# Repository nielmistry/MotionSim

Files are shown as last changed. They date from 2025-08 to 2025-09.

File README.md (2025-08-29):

# DIY Motion Simulator

This project provides a comprehensive guide to building a low-cost DIY motion simulator for flying RC planes and simulator games. Combining woodworking and mechatronics, it offers an affordable alternative to commercial options. The documentation includes CAD models, detailed assembly instructions, and software setup.

Support This Project: [Patreon](https://patreon.com/MichaelRechtin)

## Features
- Compatible with flight simulation games like Microsoft Flight Simulator 2020/2024 and WarThunder.
- Support for RC planes using ArduPilot.
- Modular design for portability, using a universal joint for base and chair connection.
- Open-source software and hardware design.

## Disclaimer
This is a DIY project; individual modifications may be necessary due to part availability or unique requirements. Ensure proper safety precautions, and consult professionals when needed. The author is not liable for any issues arising from the build.

## Getting Started
1. **CAD Models**: Access the full CAD design [here](https://cad.onshape.com/documents/14465a5308115755a641bf91/w/473302792caf9fe5237c9eca/e/42b5f99c290e18c70798f158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).
2. **Bill of Materials**: Refer to the detailed parts list in the documentation for all required components.
3. **Tools Required**:
   - Saws (e.g., circular, jigsaw, CNC router)
   - Power drill, impact driver
   - Soldering iron, 3D printer

## Assembly
The simulator comprises two main parts:
- **Base Assembly**: Includes motor mounts, universal joint, and support structures.
- **Chair Assembly**: Features side panels, foot supports, and a universal joint for connection to the base.

Follow the detailed step-by-step instructions in the documentation.

## Electronics and Wiring
The wiring for the simulator includes:
- Motion base wiring for motors and drivers.
- Side compartment wiring for controller integration.
- Back panel connectors for ease of disassembly.

Ensure proper orientation and connections for the MPU6050 sensor and other components.

## Software Setup
- **Teensy 4.0**: Flash the provided C++ code to control pitch and roll motors.
- **Raspberry Pi**: Configure USB flight controls and autorun scripts for seamless operation.
- **PC Integration**: Install necessary Python packages for supported games. Full code and instructions are available on the [GitHub repository](https://github.com/MichaelRechtin/MotionSim).

## Supported Games and Modes
- **Simulator Games**: Microsoft Flight Simulator 2020/2024, WarThunder
- **RC Planes**: Integration with Ardupilot and MAVLINK configurations

## Additional Features
- Optional integration with Buttkicker for enhanced gaming experience.
- Flexible wiring options for custom setups.

## Resources
- [Detailed Documentation](./DIY%20Motion%20Simulator%20Documentation.pdf)
- [PCB CI/CD Documentation](./docs/PCB_CI_CD.md) - Automated PCB manufacturing file generation
- [GitHub Repository](https://github.com/MichaelRechtin/MotionSim)
- [Bill of Materials](#)

### PCB Manufacturing

This repository includes automated CI/CD workflows for generating PCB manufacturing files:

- **Automated Gerber Generation**: Manufacturing files are automatically generated from KiCad PCB designs
- **Release Management**: Semantic versioning triggers automatic GitHub releases with PCB files
- **Local Generation**: Use `./generate-pcb-files.sh` to generate files locally

See [PCB CI/CD Documentation](./docs/PCB_CI_CD.md) for detailed information.

---

Feel free to explore, modify, and enjoy your DIY Motion Simulator!

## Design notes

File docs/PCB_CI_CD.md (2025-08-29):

# PCB CI/CD Workflows

This repository includes automated CI/CD workflows for generating manufacturing files from KiCad PCB designs.

## 🔧 Automated Workflows

### Pull Request Workflow (`pcb-build.yml`)

**Triggers:** When PCB files in `MotionSimPCB/` are modified in pull requests

**Generates:**
- PDF files from schematics and PCB layout
- Gerber files for PCB manufacturing
- Excellon drill files
- Manufacturing-ready ZIP packages

**Output:** GitHub Actions artifacts with download links automatically posted as PR comments

### Release Workflow (`release.yml`)

**Triggers:** When semantic version tags are pushed (e.g., `v1.0.0`, `v2.1.3`)

**Generates:**
- Versioned PDFs package
- Manufacturing files package
- Complete package with all files
- GitHub release with attached files

**Output:** GitHub release page with downloadable manufacturing files

### Test Workflow (`test-pcb.yml`)

**Triggers:** Manual dispatch or when workflow files are modified

**Purpose:** Validates KiCad setup and tests generation capabilities

## 📁 Generated Files

### PDFs
- `MotionSimPCB-schematic.pdf` - Main schematic diagram
- `controllers-schematic.pdf` - Controllers schematic diagram
- `MotionSimPCB-pcb.pdf` - PCB layout (when generation succeeds)

### Manufacturing Files
- `*.gbr` files - Gerber files for each PCB layer
- `*.drl` files - Excellon drill files
- ZIP packages ready for PCB manufacturers

## 🚀 Usage

### For Contributors (Pull Requests)

1. Modify PCB files in `MotionSimPCB/` directory
2. Create a pull request
3. Wait for CI to complete (usually 2-5 minutes)
4. Download artifacts from the PR comment links
5. Review generated PDFs and manufacturing files

### For Releases

1. Ensure all changes are merged to main branch
2. Create a semantic version tag:
   ```bash
   git tag v1.0.0
   git push origin v1.0.0
   ```
3. GitHub will automatically create a release with manufacturing files
4. Release files are ready for PCB manufacturers

### For Local Generation

Use the included script for local generation:

```bash
./generate-pcb-files.sh
```

**Requirements:**
- Docker installed and running
- PCB files in `MotionSimPCB/` directory

## 🛠️ Manual PCB Manufacturing

If automated generation fails or you prefer manual control:

### Using KiCad GUI

1. **Install KiCad** (version 9.0 or compatible)

2. **Open PCB file:**
   - Launch KiCad
   - Open `MotionSimPCB/MotionSimPCB.kicad_pcb`

3. **Generate Gerber files:**
   - Go to `File > Fabrication Outputs > Gerbers`
   - Select layers:
     - F.Cu (Front Copper)
     - B.Cu (Back Copper)
     - F.Paste (Front Paste)
     - B.Paste (Back Paste)
     - F.Silkscreen (Front Silkscreen)
     - B.Silkscreen (Back Silkscreen)
     - F.Mask (Front Solder Mask)
     - B.Mask (Back Solder Mask)
     - Edge.Cuts (Board Outline)
   - Click "Plot"

4. **Generate drill files:**
   - Go to `File > Fabrication Outputs > Drill Files`
   - Select Excellon format
   - Click "Generate Drill File"

5. **Package for manufacturer:**
   - Zip all `.gbr` and `.drl` files
   - Send to your PCB manufacturer

### PCB Specifications

- **Type:** 2-layer PCB
- **Thickness:** 1.6mm (standard)
- **Surface Finish:** HASL or ENIG recommended
- **Solder Mask:** Green (standard)
- **Silkscreen:** White
- **Via Fill:** Tented vias recommended

## 🔍 Troubleshooting

### Common Issues

**"KiCad generation failed"**
- The workflow will fall back to existing PDFs
- Check the Actions log for detailed error messages
- Use the local generation script for debugging

**"No artifacts available"**
- Ensure PCB files were actually modified in the PR
- Check that file paths match `MotionSimPCB/**`

**Permission errors in local generation**
- Ensure Docker has sufficient permissions
- Try running with `sudo` if necessary
- Check that PCB files are readable

### Getting Help

1. Check the GitHub Actions logs for detailed error messages
2. Review the PCB files for any format compatibility issues
3. Try the local generation script to isolate Docker issues
4. Open an issue if problems persist

## 🔄 Updating Workflows

The workflows are designed to be robust and self-contained. Key features:

- **Fallback mechanisms:** Uses existing PDFs if generation fails
- **Version compatibility:** Uses KiCad 9.0 matching the file format
- **Error handling:** Graceful degradation with informative messages
- **Local testing:** Standalone script for development and debugging

## 📋 File Structure

```
MotionSimPCB/
├── MotionSimPCB.kicad_pcb    # Main PCB layout
├── MotionSimPCB.kicad_sch    # Main schematic
├── controllers.kicad_sch     # Controllers schematic
├── MotionSimPCB.kicad_pro    # Project file
└── pdfs/                     # Existing PDFs (fallback)
    └── MotionSimPCB.pdf

assets/                       # Generated files (gitignored)
├── pdfs/                     # Generated PDFs
├── gerbers/                  # Generated Gerber files
└── drill/                    # Generated drill files

.github/workflows/
├── pcb-build.yml            # PR workflow
├── release.yml              # Release workflow
└── test-pcb.yml             # Test workflow

generate-pcb-files.sh        # Local generation script
```

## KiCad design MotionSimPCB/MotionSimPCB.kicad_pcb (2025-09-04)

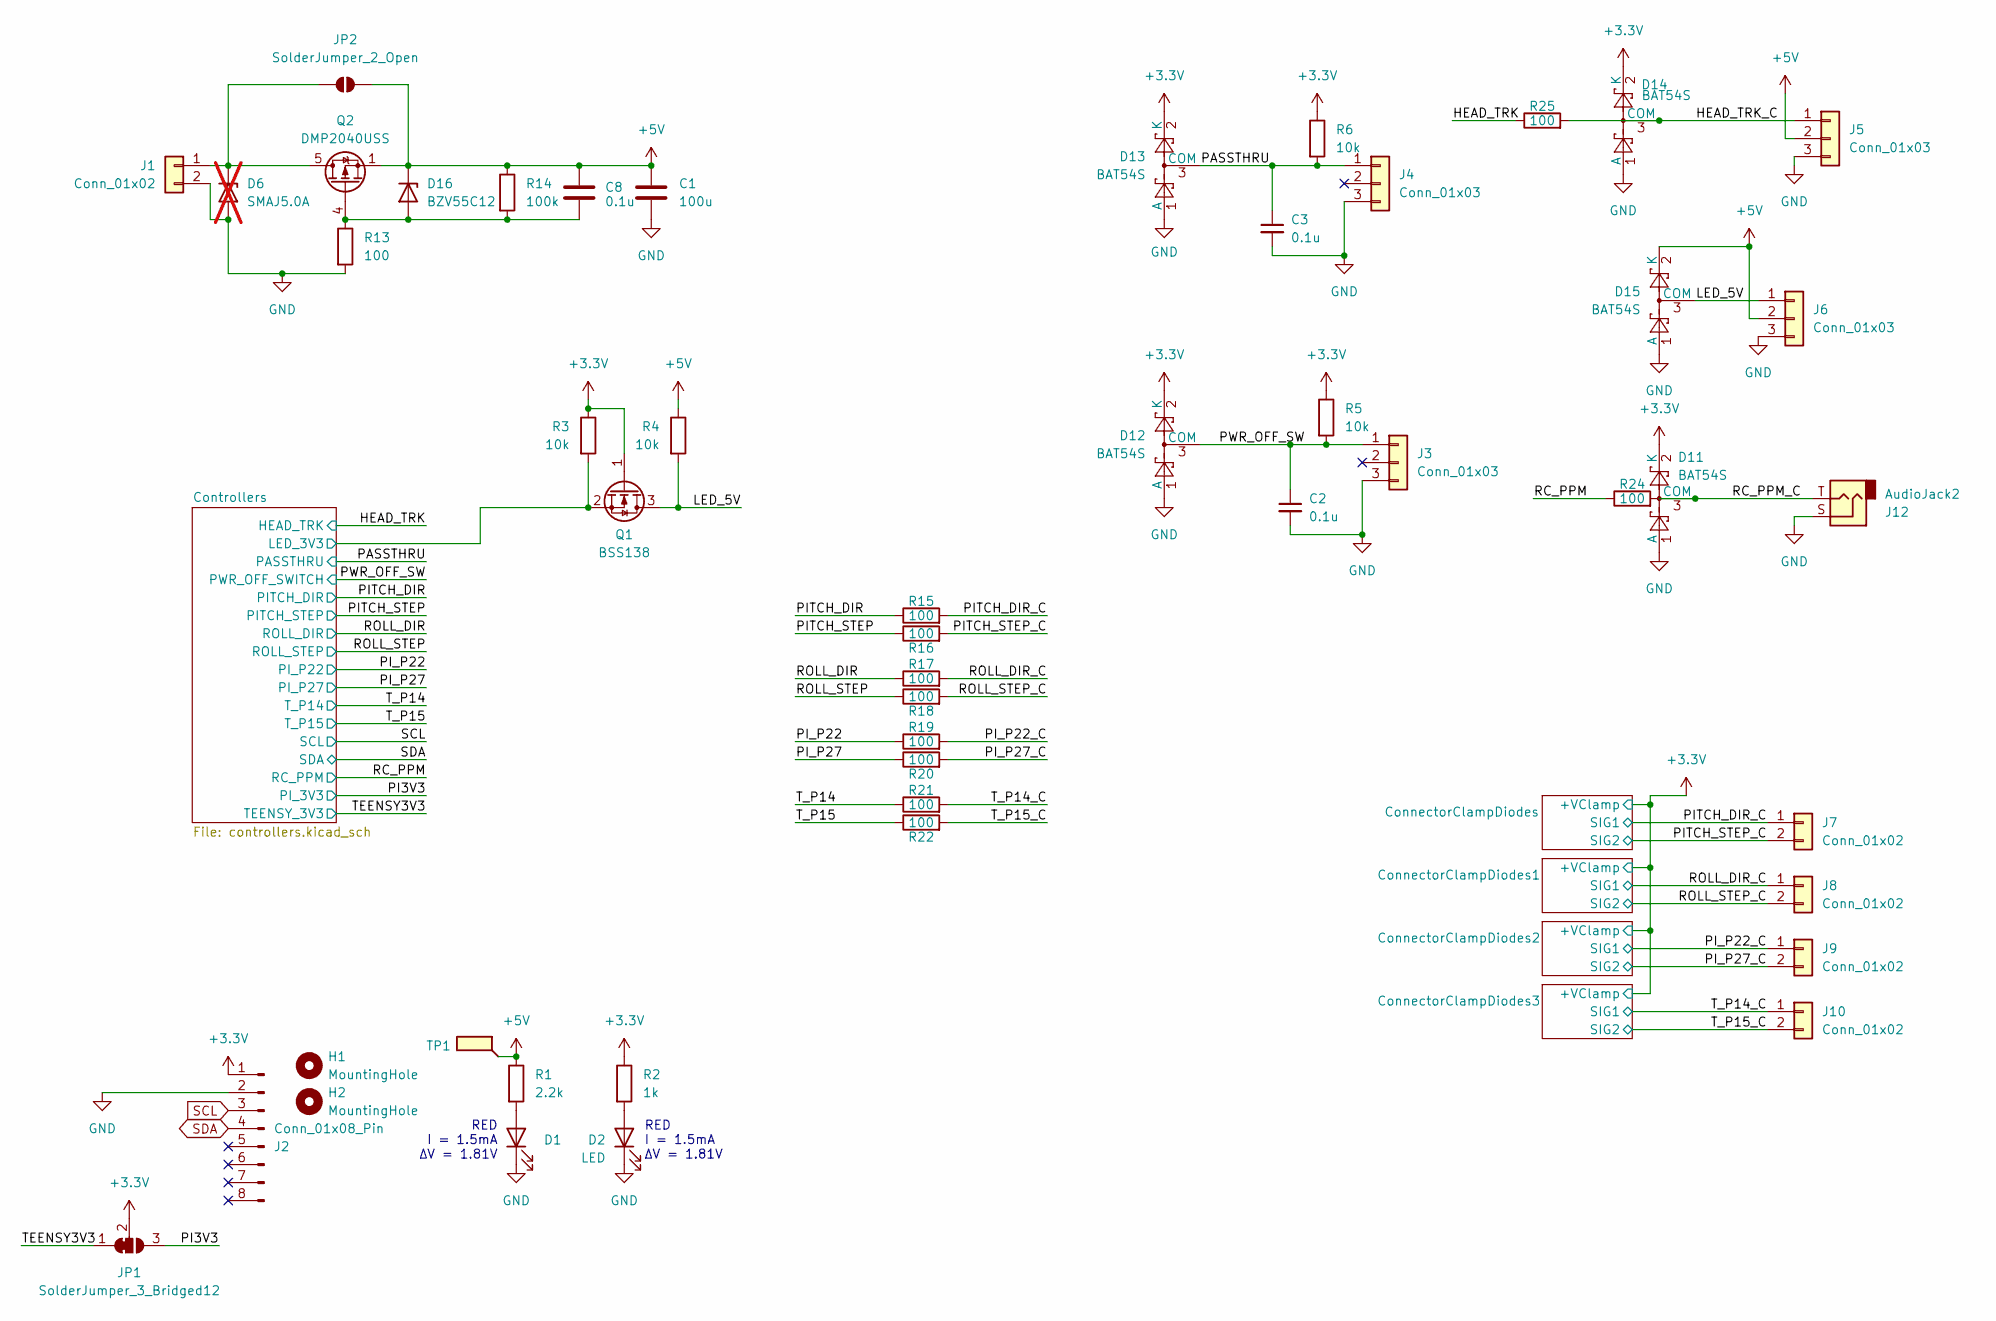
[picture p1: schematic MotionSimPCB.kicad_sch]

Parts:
C1: 100u; C_Radial_D6.3mm_H5.0mm_P2.50mm
C2, C3: 0.1u; C_0805_2012Metric
C8: 0.1u; C_0603_1608Metric
D1, D2: LED; D_0805_2012Metric; JLC PN C2286
D6: SMAJ5.0A; D_SMA; not fitted
D11, D12, D13, D14, D15: BAT54S; SOT-23
D16: BZV55C12; D_MiniMELF
H1, H2: MountingHole; MountingHole_2.7mm_M2.5
J1, J7, J8, J9, J10: Conn_01x02; TerminalBlock_Phoenix_MKDS-1,5-2_1x02_P5.00mm_Horizontal
J2: Conn_01x08_Pin; PinSocket_1x08_P2.54mm_Vertical
J3, J4, J5, J6: Conn_01x03; JST_XH_B3B-XH-AM_1x03_P2.50mm_Vertical
J12: AudioJack2
JP1: SolderJumper_3_Bridged12; SolderJumper-3_P1.3mm_Bridged2Bar12_RoundedPad1.0x1.5mm
JP2: SolderJumper_2_Open; SolderJumper-2_P1.3mm_Open_TrianglePad1.0x1.5mm
Q1: BSS138; SOT-23
Q2: DMP2040USS; SOIC-8_3.9x4.9mm_P1.27mm
R1: 2.2k; R_0805_2012Metric
R2: 1k; R_0805_2012Metric
R3, R4, R5, R6: 10k; R_0805_2012Metric
R13, R15, R16, R17, R18, R19, R20, R21, R22, R24, R25: 100; C_0603_1608Metric
R14: 100k; C_0603_1608Metric
TP1: TestPoint_Flag; TestPoint_Pad_D2.0mm

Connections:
+3.3V: D11.2 (K), D12.2 (K), D13.2 (K), D14.2 (K), J2.1, JP1.2 (C), Q1.1 (G), R2.1, R3.1, R5.1, R6.1; also elsewhere on the board
+5V: C1.1, C8.1, D15.2 (K), D16.1 (K), J5.2, J6.2, JP2.2 (B), Q2.1 (S), Q2.2 (S), Q2.3 (S), R1.1, R4.1, R14.1, TP1.1; also elsewhere on the board
/Controllers/LED_3V3: Q1.2 (S), R3.2; also elsewhere on the board
/HEAD_TRK: R25.1; also elsewhere on the board
/HEAD_TRK_C: D14.3 (COM), J5.1, R25.2
/LED_5V: D15.3 (COM), J6.1, Q1.3 (D), R4.2
/PASSTHRU: C3.1, D13.3 (COM), J4.1, R6.2; also elsewhere on the board
/PI3V3: JP1.3 (B); also elsewhere on the board
/PITCH_DIR: R15.1; also elsewhere on the board
/PITCH_DIR_C: J7.1, R15.2; also elsewhere on the board
/PITCH_STEP: R16.1; also elsewhere on the board
/PITCH_STEP_C: J7.2, R16.2; also elsewhere on the board
/PI_P22: R19.1; also elsewhere on the board
/PI_P22_C: J9.1, R19.2; also elsewhere on the board
/PI_P27: R20.1; also elsewhere on the board
/PI_P27_C: J9.2, R20.2; also elsewhere on the board
/PWR_OFF_SW: C2.1, D12.3 (COM), J3.1, R5.2; also elsewhere on the board
/RC_PPM: R24.1; also elsewhere on the board
/RC_PPM_C: D11.3 (COM), J12.T, R24.2
/ROLL_DIR: R17.1; also elsewhere on the board
/ROLL_DIR_C: J8.1, R17.2; also elsewhere on the board
/ROLL_STEP: R18.1; also elsewhere on the board
/ROLL_STEP_C: J8.2, R18.2; also elsewhere on the board
/TEENSY3V3: JP1.1 (A); also elsewhere on the board
/T_P14: R21.1; also elsewhere on the board
/T_P14_C: J10.1, R21.2; also elsewhere on the board
/T_P15: R22.1; also elsewhere on the board
/T_P15_C: J10.2, R22.2; also elsewhere on the board
GND: C1.2, C2.2, C3.2, D1.1 (K), D2.1 (K), D6.2 (A2), D11.1 (A), D12.1 (A), D13.1 (A), D14.1 (A), D15.1 (A), J1.2, J2.2, J3.3, J4.3, J5.3, J6.3, J12.S, R13.2; also elsewhere on the board
unnamed: D1.2 (A), R1.2
unnamed: D2.2 (A), R2.2
unnamed: D6.1 (A1), J1.1, JP2.1 (A), Q2.5 (D), Q2.6 (D), Q2.7 (D), Q2.8 (D)
unnamed: C8.2, D16.2 (A), Q2.4 (G), R13.1, R14.2
SCL: J2.3; also elsewhere on the board
SDA: J2.4; also elsewhere on the board

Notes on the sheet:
RED I = 1.5mA ΔV = 1.81V

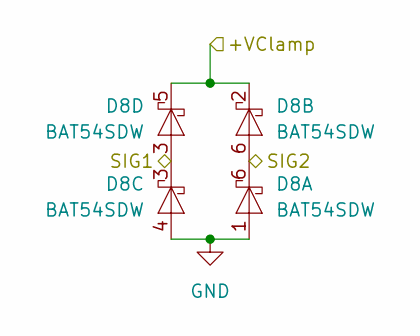
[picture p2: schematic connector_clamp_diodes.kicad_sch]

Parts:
D8: BAT54SDW; SOT-363_SC-70-6

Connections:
+3.3V: D8.2 (K), D8.5 (K); also elsewhere on the board
/PITCH_DIR_C: D8.3 (K); also elsewhere on the board
/PITCH_STEP_C: D8.6 (K); also elsewhere on the board
GND: D8.1 (A), D8.4 (A); also elsewhere on the board

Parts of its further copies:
D7, D9, D10: BAT54SDW; SOT-363_SC-70-6

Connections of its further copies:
+3.3V: D7.2 (K), D7.5 (K), D9.2 (K), D9.5 (K), D10.2 (K), D10.5 (K); also elsewhere on the board
/PI_P22_C: D9.3 (K); also elsewhere on the board
/PI_P27_C: D9.6 (K); also elsewhere on the board
/ROLL_DIR_C: D7.3 (K); also elsewhere on the board
/ROLL_STEP_C: D7.6 (K); also elsewhere on the board
/T_P14_C: D10.3 (K); also elsewhere on the board
/T_P15_C: D10.6 (K); also elsewhere on the board
GND: D7.1 (A), D7.4 (A), D9.1 (A), D9.4 (A), D10.1 (A), D10.4 (A); also elsewhere on the board

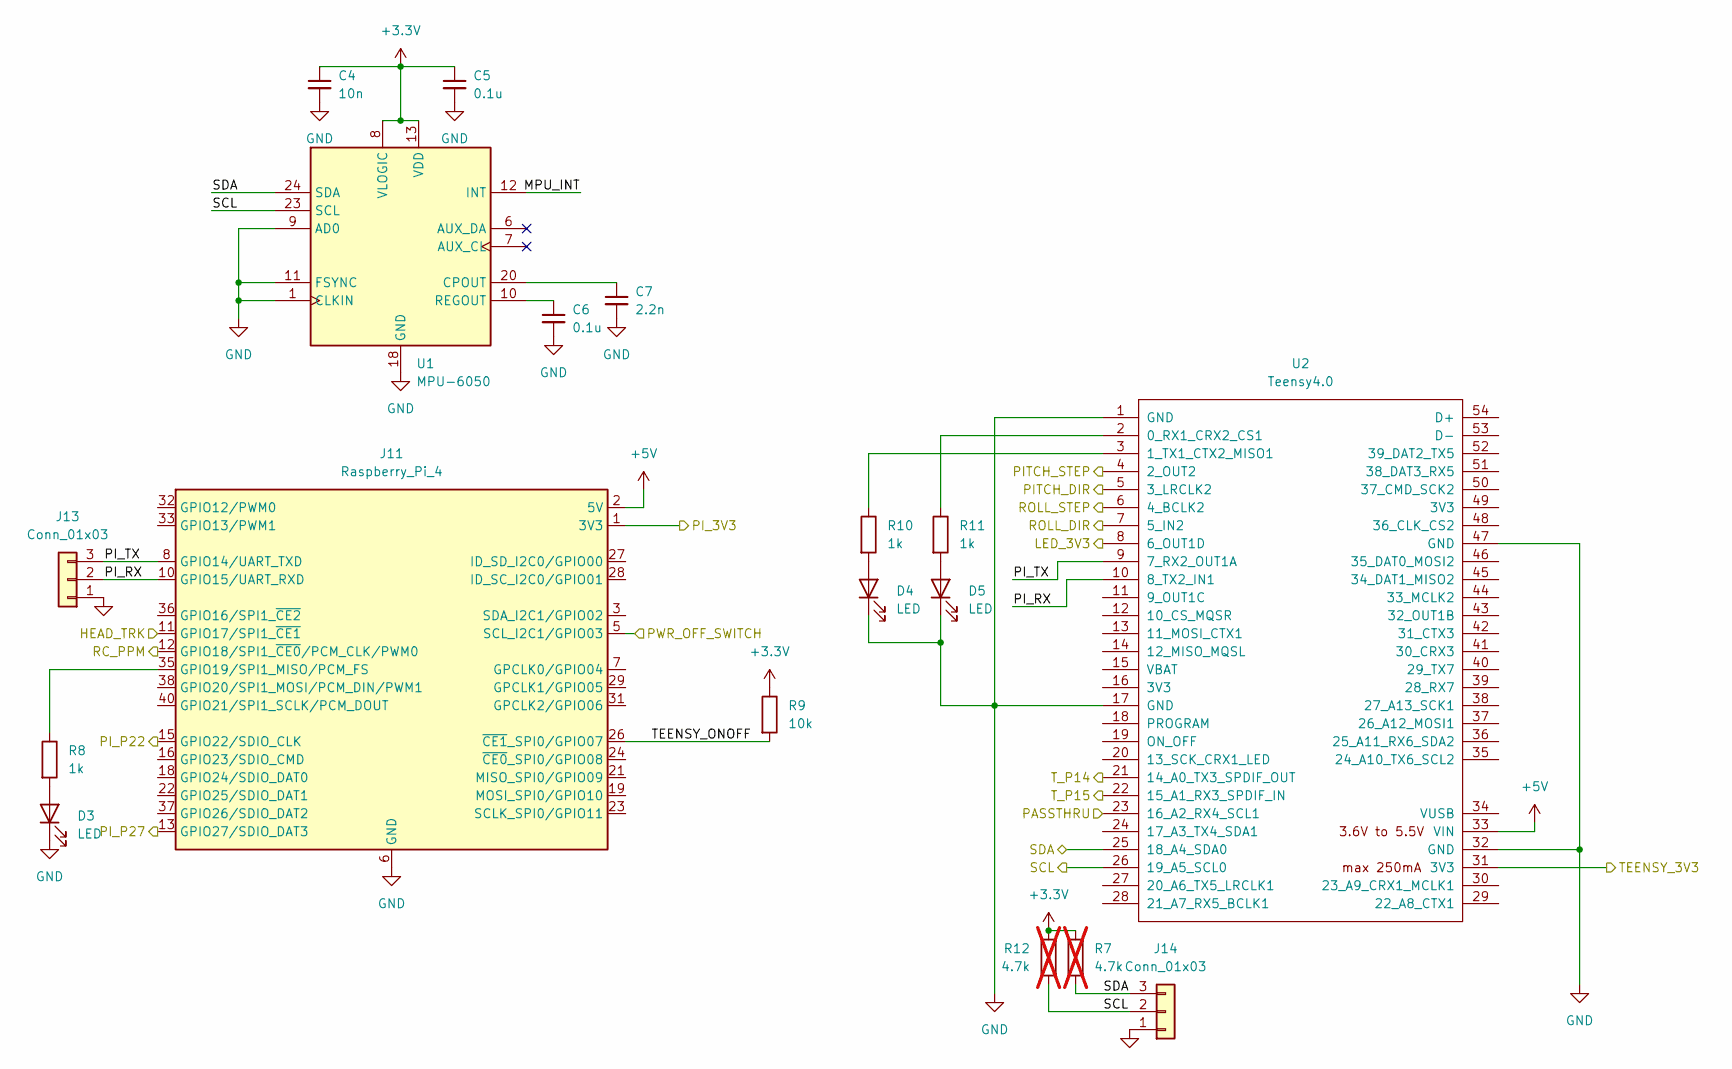
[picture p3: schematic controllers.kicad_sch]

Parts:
C4: 10n; C_0603_1608Metric
C5, C6: 0.1u; C_0603_1608Metric
C7: 2.2n; C_0603_1608Metric
D3, D4, D5: LED; D_0805_2012Metric; JLC PN C2289
J11: Raspberry_Pi_4; raspberrypi_2_3
J13, J14: Conn_01x03; PinHeader_1x03_P2.54mm_Vertical
R7, R12: 4.7k; R_0805_2012Metric; not fitted
R8, R10, R11: 1k; R_0805_2012Metric
R9: 10k; R_0805_2012Metric
U1: MPU-6050; InvenSense_QFN-24_4x4mm_P0.5mm
U2: Teensy4.0; Teensy40

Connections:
+3.3V: C4.1, C5.1, R7.1, R9.1, R12.1, U1.8 (VLOGIC), U1.13 (VDD); also elsewhere on the board
+5V: J11.2 (5V), J11.4 (5V), U2.33 (VIN); also elsewhere on the board
/Controllers/LED_3V3: U2.8 (6_OUT1D); also elsewhere on the board
/Controllers/MPU_INT: U1.12 (INT)
/Controllers/PI_RX: J11.10 (GPIO15/UART_RXD), J13.2, U2.10 (8_TX2_IN1)
/Controllers/PI_TX: J11.8 (GPIO14/UART_TXD), J13.3, U2.9 (7_RX2_OUT1A)
/Controllers/TEENSY_ONOFF: J11.26 (~CE1_SPI0/GPIO07), R9.2
/HEAD_TRK: J11.11 (GPIO17/SPI1_~CE1); also elsewhere on the board
/PASSTHRU: U2.23 (16_A2_RX4_SCL1); also elsewhere on the board
/PI3V3: J11.1 (3V3), J11.17 (3V3); also elsewhere on the board
/PITCH_DIR: U2.5 (3_LRCLK2); also elsewhere on the board
/PITCH_STEP: U2.4 (2_OUT2); also elsewhere on the board
/PI_P22: J11.15 (GPIO22/SDIO_CLK); also elsewhere on the board
/PI_P27: J11.13 (GPIO27/SDIO_DAT3); also elsewhere on the board
/PWR_OFF_SW: J11.5 (SCL_I2C1/GPIO03); also elsewhere on the board
/RC_PPM: J11.12 (GPIO18/SPI1_~CE0/PCM_CLK/PWM0); also elsewhere on the board
/ROLL_DIR: U2.7 (5_IN2); also elsewhere on the board
/ROLL_STEP: U2.6 (4_BCLK2); also elsewhere on the board
/TEENSY3V3: U2.31 (3V3); also elsewhere on the board
/T_P14: U2.21 (14_A0_TX3_SPDIF_OUT); also elsewhere on the board
/T_P15: U2.22 (15_A1_RX3_SPDIF_IN); also elsewhere on the board
GND: C4.2, C5.2, C6.2, C7.2, D3.1 (K), D4.1 (K), D5.1 (K), J11.6 (GND), J11.9 (GND), J11.14 (GND), J11.20 (GND), J11.25 (GND), J11.30 (GND), J11.34 (GND), J11.39 (GND), J13.1, J14.1, U1.1 (CLKIN), U1.9 (AD0), U1.11 (FSYNC), U1.18 (GND), U2.1 (GND), U2.17 (GND), U2.32 (GND), U2.47 (GND); also elsewhere on the board
unnamed: D3.2 (A), R8.2
unnamed: D4.2 (A), R10.2
unnamed: D5.2 (A), R11.2
unnamed: J11.35 (GPIO19/SPI1_MISO/PCM_FS), R8.1
unnamed: C7.1, U1.20 (CPOUT)
unnamed: C6.1, U1.10 (REGOUT)
unnamed: R11.1, U2.2 (0_RX1_CRX2_CS1)
unnamed: R10.1, U2.3 (1_TX1_CTX2_MISO1)
SCL: J14.2, R12.2, U1.23 (SCL), U2.26 (19_A5_SCL0); also elsewhere on the board
SDA: J14.3, R7.2, U1.24 (SDA), U2.25 (18_A4_SDA0); also elsewhere on the board

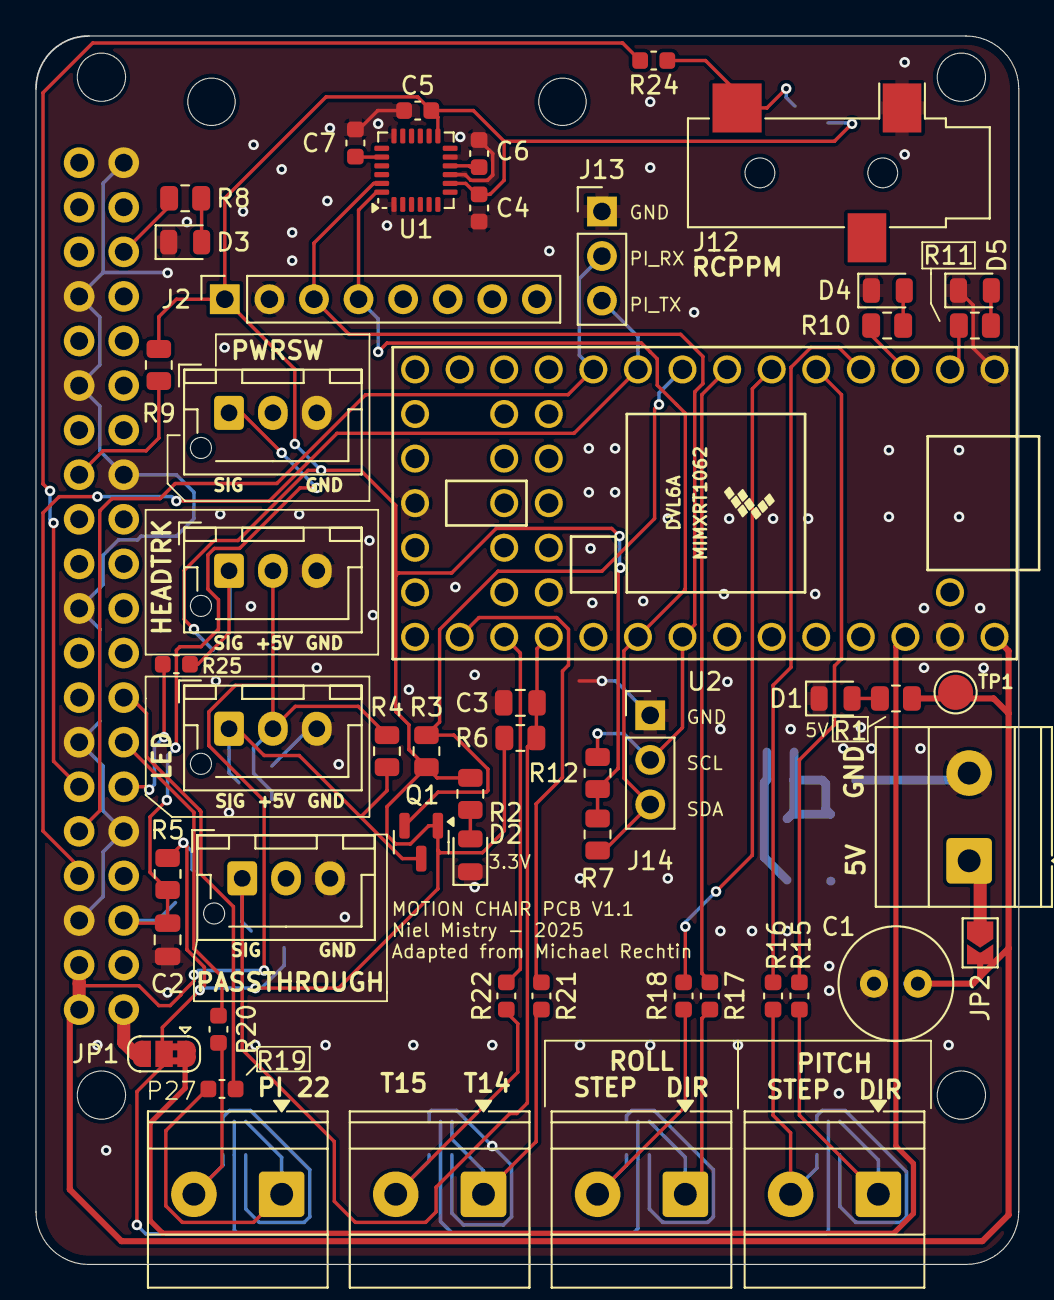
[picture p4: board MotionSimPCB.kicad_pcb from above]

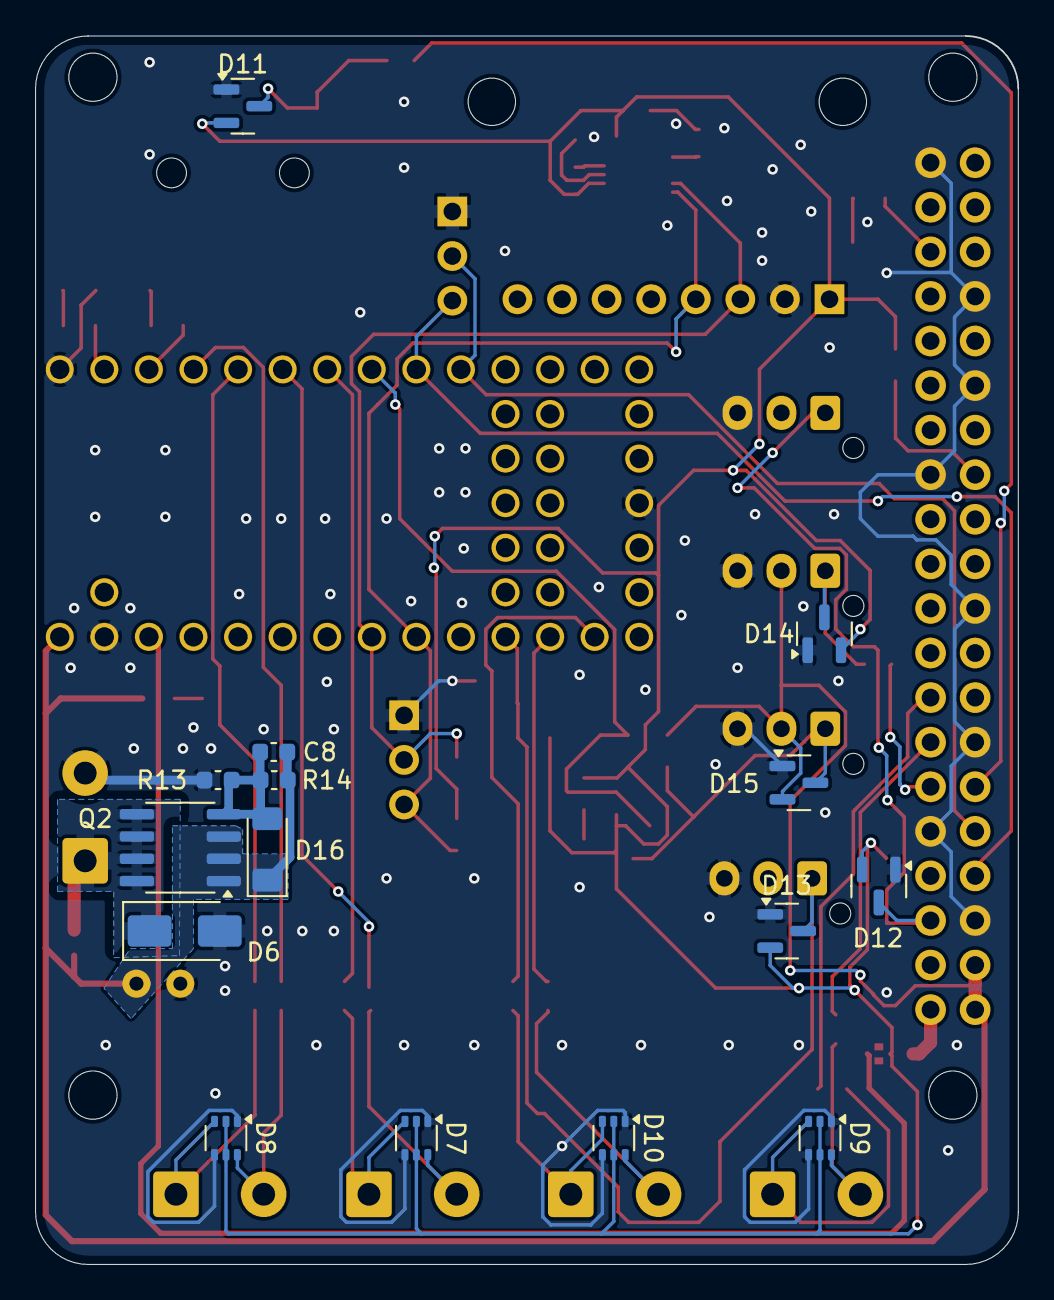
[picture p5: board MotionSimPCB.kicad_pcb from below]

Board: 2 copper layers, 56.0 x 70.0 mm, 71 parts (15 on the bottom side), 46 nets.

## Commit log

2025-08-26 first commit of pcb
    [MotionSimPCB.kicad_pcb, MotionSimPCB.kicad_sch, controllers.kicad_sch]
2025-08-26 round corners
    [MotionSimPCB.kicad_pcb]
2025-08-26 cleanup silkscreen
    [MotionSimPCB.kicad_pcb]
2025-08-28 fix drc, add protection
    [MotionSimPCB.kicad_pcb, MotionSimPCB.kicad_sch, connector_clamp_diodes.kicad_sch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]
2025-08-28 fix some issues
    [MotionSimPCB.kicad_pcb, MotionSimPCB.kicad_sch]
2025-08-28 Add GitHub Actions workflows for PCB CI/CD
2025-08-28 Implement robust PCB CI/CD with fallback mechanisms
2025-08-28 Rebase on PCB branch and update workflow targets
2025-08-28 Fix PCB file generation and artifact URL issues
2025-08-30 fix clearance
    [MotionSimPCB.kicad_pcb, MotionSimPCB.kicad_sch, controllers.kicad_sch]
2025-09-04 DNP D6
    [MotionSimPCB.kicad_pcb, MotionSimPCB.kicad_sch]
